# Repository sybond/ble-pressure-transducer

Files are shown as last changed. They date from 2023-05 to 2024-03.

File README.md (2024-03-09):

# Bluetooth Pressure Transducer
The purpose of this project is to create Bluetooth Pressure Transducer that can be connected to pressure profiling apps (SE Profiler, Coffee Flow & Odyssey Espresso).

The target espresso machine was my Flair 58. This espresso maker has a G1/8 fitting for the pressure gauge.

## Diagram
Following diagram depict the configuration of the current implementation.

```mermaid
flowchart BT
    A(Analog Pressure\nTransmitter) <-->|wired| B(ESP32 Dev Board)
    B<.->|BLE/Bluetooth|C(Android/iPhone\nSE Profiler, Coffee Flow, Odyssey Espresso Apps)
```

## Bill of Material
This device consist of following components:
- ESP32 Dev board (WEMOS LOLIN32 OLED)
- Breadboard
- Analog Pressure Transmitter 5V DC

### ESP32 Dev board (WEMOS LOLIN32 OLED)
I'm using this board because there is OLED embedded in the board so we just need the programming part without having trouble to do wiring on display component.

The display component will be used to display the current status of the device. Whether connected to the app or not. Also to display current pressure reading by the analog pin.

ESP32 LOLIN32

ESP32 LOLIN32

### Analog Pressure Transmitter 5V DC
`WARNING: Make sure youre using high temperature version of the sensors before using it with your espresso machine`

The analog pressure transmitter wiring will have :
- 5V (power)
- Ground
- Output

[@frontmesh](https://github.com/frontmesh) has provided some information regarding two types of G1/8 fittings, short and long. I'm guessing Flair 58 is using the lengthy version. It would be preferable if you could have this long-fitting version &mdash; and please share it with us.

### Wiring
From above schematic, we will need to connect Pressure Transmitter to `5V`, `GND` and some analog PIN (I choose `ADC19`/`GPIO26`).

### Code Part
At the moment I will put only the binary to this repository. However the snippet for pressure calculation is availbale in the repository.

### Flashing Firmware using ESPTOOL
Download the binary provided in the release section. The binary will consists of following files:
1. `BluetoothPressureTransducer_InternalLCD.ino.bootloader.bin`
2. `BluetoothPressureTransducer_InternalLCD.ino.partitions.bin`
3. `BluetoothPressureTransducer_InternalLCD.ino.bin`
4. `boot_app0.bin` (this files should be provided by ESPTOOL during package installation - make sure your environment already have running Arduino IDE with ESP32 pack)

Run following command (some parts will need you to adjust to match your own environment):

```shell
{PATH_TO_ESPTOOL}/esptool --chip esp32 --port "{CHANGE_TO_YOUR_DEVICE_PORT}" --baud 115200  --before default_reset --after hard_reset write_flash  -z --flash_mode dio --flash_freq 80m --flash_size 4MB 0x1000 BluetoothPressureTransducer_InternalLCD.ino.bootloader.bin 0x8000 BluetoothPressureTransducer_InternalLCD.ino.partitions.bin 0xe000 "{PATH_TO_YOUR_ESP32_PACKAGE}/packages/esp32/hardware/esp32/2.0.7/tools/partitions/boot_app0.bin" 0x10000 BluetoothPressureTransducer_InternalLCD.ino.bin
```

For your reference, in my environment (OSX) will need to run using following parameters:
```shell
"/Users/sybond/Library/Arduino15/packages/esp32/tools/esptool_py/4.5.1/esptool" --chip esp32 --port "/dev/cu.usbserial-0001" --baud 115200  --before default_reset --after hard_reset write_flash  -z --flash_mode dio --flash_freq 80m --flash_size 4MB 0x1000 "/private/var/folders/pz/jkl6w3fs45v88wcck8qtfhw00000gn/T/arduino/sketches/4E4A8C476EDC2D7C933461960E7BD641/BluetoothPressureTransducer_InternalLCD.ino.bootloader.bin" 0x8000 "/private/var/folders/pz/jkl6w3fs45v88wcck8qtfhw00000gn/T/arduino/sketches/4E4A8C476EDC2D7C933461960E7BD641/BluetoothPressureTransducer_InternalLCD.ino.partitions.bin" 0xe000 "/Users/sybond/Library/Arduino15/packages/esp32/hardware/esp32/2.0.7/tools/partitions/boot_app0.bin" 0x10000 "/private/var/folders/pz/jkl6w3fs45v88wcck8qtfhw00000gn/T/arduino/sketches/4E4A8C476EDC2D7C933461960E7BD641/BluetoothPressureTransducer_InternalLCD.ino.bin"
```
Currently I have 2 versions of firmware:
1. For 0-200psi pressure transmitter (discontinued)
2. For 0-1,6MPa pressure transmitter (I recently purchase from [here](https://www.aliexpress.com/item/1005004559608411.html); make sure to put note about G1/8 fitting)

## Config Characteristic
Latest version of the firmware, now support of write Config Characteristic (`873ae82d-4c5a-4342-b539-9d900bf7ebd0`). The purpose of this characteristic is to able customized sensor reading based on the manual calibration. The characteristic expecting following data:

| Config parameter | Format | Sample |
|:---|:---| :--- |
| minADC | `00 {4 bytes int}` | `00 c7 01 00 00` = set minVoltage to 455|
| maxADC | `01 {4 bytes int}` | `01 34 0d 00 00` = set maxADC to 3380|
| maxMilibar | `02 {8 bytes long}` | `02 80 3e 00 00 00 00 00 00` = set maxMilibar to 16000|

The parameters will be involved into following calculation to determine pressure value:

`pressure in milibar =  (analogReading - minADC) * (maxMilibar) / (maxADC - minADC);`

Following is the default parameters value:
1. Minimum ADC (`minADC` default value is `455`)
2. Maximum ADC (`maxADC` default value is `3380`)
3. Maximum milibar (`maxMilibar` default value is `9000`)

The default value is the working parameter for current pressure sensor I use (0.5V-4,5V, 0-1,6Mpa).

## Serial Config Interface
Other option starting from v3.0, you can configure the parameters via serial interface.

1. Just connect to the ESP32 Bluetooth using Serial Bluetooth Terminal ([Android](https://play.google.com/store/apps/details?id=de.kai_morich.serial_bluetooth_terminal)) or another similiar apps.
2. Type `info`. The syntax structure should be self explaining from this point.

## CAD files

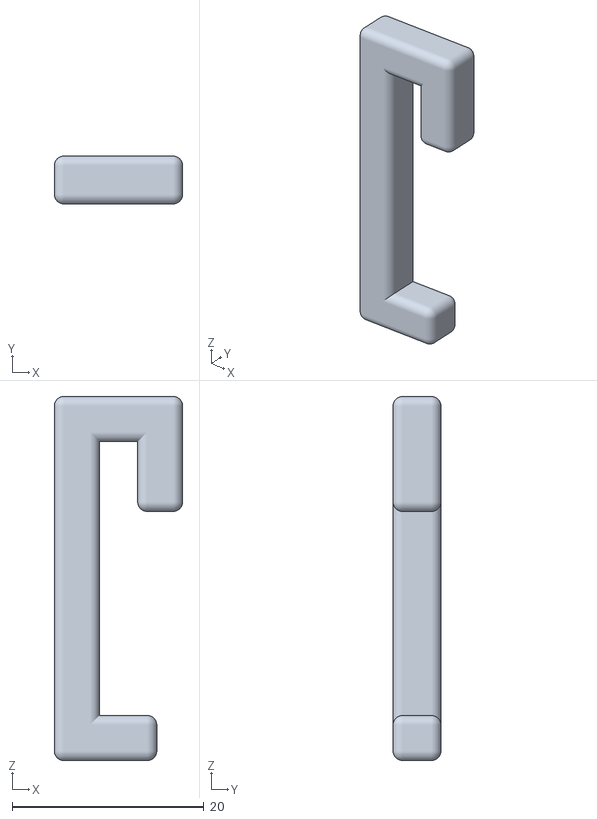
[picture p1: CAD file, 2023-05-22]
WEMOSLolin32_Case/skadisHook.stl
13.4 x 5.00 x 38.0

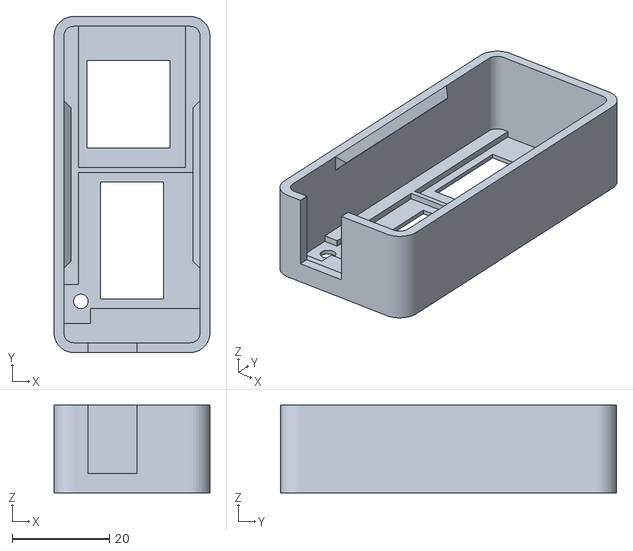
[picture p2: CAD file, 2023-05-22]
WEMOSLolin32_Case/Lolin32 Box v2.stl
32.0 x 69.0 x 18.0

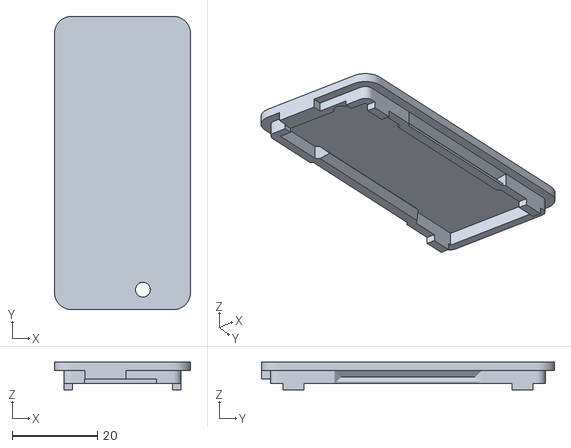
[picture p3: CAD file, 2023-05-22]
WEMOSLolin32_Case/esp32_oled_cover_param.stl
32.0 x 69.0 x 6.50

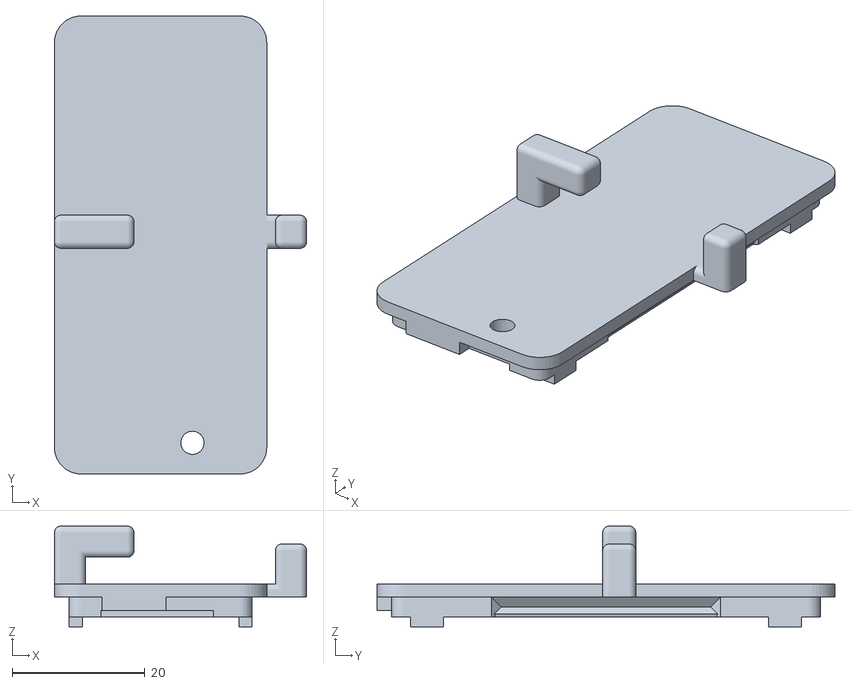
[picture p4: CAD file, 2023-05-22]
WEMOSLolin32_Case/Lolin32 Cover v2.stl
38.0 x 69.0 x 15.2

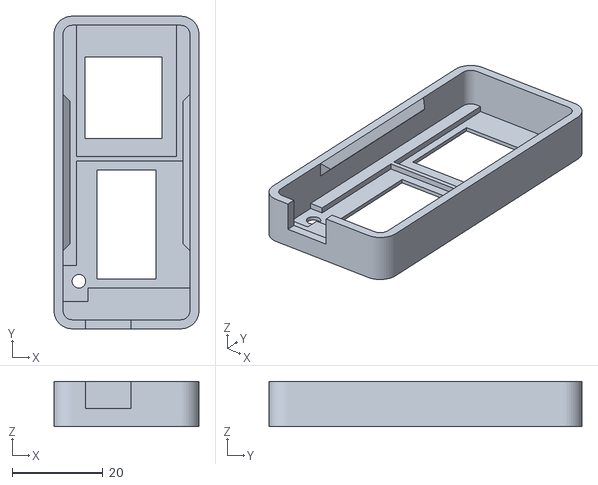
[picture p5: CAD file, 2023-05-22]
WEMOSLolin32_Case/esp32_oled_box_param.stl
32.0 x 69.0 x 10.0

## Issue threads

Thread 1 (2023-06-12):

Flair58 connector

frontmesh, 2023-06-12:
Hi @sybond ,

I've seen your post in some of the groups and was wondering to try this out with my Flair 58.
Transducer which you purchased (as stated in README - https://www.aliexpress.com/item/1005004559608411.html) doesn't have proper flair 58 pressure thread connection. Did you have to buy some sort of adapter so that you were able to use it with your Flair 58?
Another solution to prevent leaks from the thread would be to use sealant tape which should be put on to the thread every time you change the pressure device which I am trying to avoid.

Thanks,
Vlad

sybond, 2023-06-12:
> Did you have to buy some sort of adapter so that you were able to use it with your Flair 58?

No. Make sure you ordering G1/8. They mention _"Pressure connection: 1/8”NPT, Other pressure connection is on request"_.

> Another solution to prevent leaks from the thread would be to use sealant tape which should be put on to the thread every time you change the pressure device which I am trying to avoid.

Even though I have ordered the correct G1/8, I still use seal tape to prevent leaks. In my case, I'll stick to my pressure sensor, even if I don't record the data every time.

frontmesh, 2023-06-12:
Thanks for the clarification. I have indeed received a G1/8 connection then.
What I did not release is there are two types (short and long) of G1/8 connections.
Flair uses longer connection with a rubber ring at the top which prevents leaks
https://pressensor.com/products/fitting-for-compatibility-with-g1-8-connections
and a short one https://pressensor.com/products/fitting-for-compatibility-with-g1-8-short-connections
I have another digital Elitech PGW-500 transducer which also has short G1/8 connection.

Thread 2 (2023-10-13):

Temp readings?

browntownington, 2023-10-13:
Hey there, fellow flair 58 user.. been trying to find myself a low cost pressure transducer for months and I'm very grateful to come across your project.

I noticed alot of commercially available transducers also read temp. I thought this would be cool for the flair since temp is always a guess from the kettle and the boiler. Have you considered tracking temp?

I haven't been successful in finding a transmitter that does pressure and temp. So I'm guessing an additional BSP sensor would be required.

sybond, 2023-10-25:
Hi!
Actually I was thinking to read the temp from the OEM sensor that currently only connected to the F58 controller.
I see in Facebook group discussion they are using N type thermocouple.

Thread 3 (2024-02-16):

Voltage of Pressure Transmitter

GelliFrancesco, 2024-02-16:
Hi Bondan,
Thanks a lot for your contribution, I think you are helping the community a lot!

I am looking into the 0-1,6MPa pressure transmitter you recommended:(https://www.aliexpress.com/item/1005004559608411.html)
It comes in various Voltage options: 0-3.3V, 0-5V, 1-5V and 0.5-4.5V

Which one do you recommend buying?
I see that the ESP32 kit has a 5V In pin, but I read that most ESP32 kits works only at 3.3V, hence I am a bit confused.
Thanks!

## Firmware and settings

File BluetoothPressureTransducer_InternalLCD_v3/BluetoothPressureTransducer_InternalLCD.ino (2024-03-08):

/*

 Bluetooth Pressure Transducer
 Copyright (c) 2023 Bondan Sumbodo <sybond@gmail.com>

 FOR WEMOS LOLIN32

 History:
 2023/03/23 - First version : playing with BLE characteristic
 2023/03/24 - Adding Pressure BLECharacteristic, Battery Level BLECharacteristic
            - Fix pressure data format encoding
 2023/03/30 - Rewrite for WEMOS LOLIN32 board
            - Adding logo
            - New calculation of pressure, since in LOLIN32 they have 5V input for sensor
 2023/05/01 - Allow to display pressure without waiting BLE connected
 2024/02/23 - Saving last minVoltage into NVS
 2024/02/24 - Revisit pressure calculation
            - Adding minVoltage, maxVoltage, maxMilibar to NVS
            - Adding characteristic for future use, currently to reset NVS stored value to default value
 2024/02/28 - Adding new calibrated point for ADC known value for 9 Bar pressure
 2024/03/08 - Rework on configuration part. Removing `minVoltage` and `maxVoltage`.
            - Adding serial com settings
            - All pressure calculation now should be configurable using `map(analogValue,minADC,maxADC,0,maxMilibar)`.

*/
#include <BLEDevice.h>
#include <BLEServer.h>
#include <BLEUtils.h>
#include <BLE2902.h>

#include <Adafruit_GFX.h>
#include <Adafruit_SSD1306.h>

#include <Preferences.h>

BLEServer* pServer = NULL;
BLECharacteristic* pCharPressure = NULL;
BLECharacteristic* pCharZeroPressure = NULL;
BLECharacteristic* pCharPressureConfig = NULL;
BLECharacteristic* pCharBatt = NULL;
BLECharacteristic* pCharLog = NULL;
BLECharacteristic* pCharMFC = NULL;


#define SCREEN_WIDTH 128     // OLED display width, in pixels
#define SCREEN_HEIGHT 64     // OLED display height, in pixels
#define OLED_RESET -1        // Reset pin # (or -1 if sharing Arduino reset pin)
#define SCREEN_ADDRESS 0x3C  ///< See datasheet for Address; 0x3D for 128x64, 0x3C for 128x32
Adafruit_SSD1306 display(SCREEN_WIDTH, SCREEN_HEIGHT, &Wire, OLED_RESET);

bool deviceConnected = false;
bool oldDeviceConnected = false;
bool printLog = false;
int BattLevel = 100;
int32_t value = 0xB6032823;
int32_t value2 = 0x00;
int barPotentio = 0;
int counter = 0;

float minVoltage = 0.5;
float maxVoltage = 4.5;
float currVoltage = 0;
long maxMilibar = 16000;  //default 16bar

int Potentio = 0;
float currBar = 0.0;

uint8_t pressData[4] = { 0x03, 0xb6, 0x0, 0x0 };
char text[200];
char dev_name[20];
Preferences configNVS;


#define fw_ver "v2.6 WL"

static unsigned char logosybond_led_bits[] = {
  0x00, 0x00, 0x00, 0x00, 0x00, 0x00, 0xe0, 0x01, 0x00, 0x00, 0x00, 0x70,
  0x00, 0x00, 0x00, 0x00, 0x00, 0x00, 0x00, 0xe0, 0x01, 0x00, 0x00, 0x00,
  0x70, 0x00, 0xc0, 0xff, 0xff, 0x07, 0x00, 0x00, 0xe0, 0x01, 0x00, 0x00,
  0x00, 0x70, 0x00, 0xf0, 0xff, 0xff, 0x1f, 0x00, 0x00, 0xe0, 0x01, 0x00,
  0x00, 0x00, 0x70, 0x00, 0xf8, 0xff, 0xff, 0x3f, 0x00, 0x00, 0xe0, 0x01,
  0x00, 0x00, 0x00, 0x70, 0x00, 0xfc, 0xff, 0xff, 0x7f, 0x00, 0x00, 0xe0,
  0x01, 0x00, 0x00, 0x00, 0x70, 0x00, 0x3e, 0x00, 0x00, 0x7c, 0xe0, 0x3f,
  0xfc, 0x3f, 0xfc, 0xf8, 0xc7, 0x7f, 0x00, 0x1e, 0x00, 0x00, 0xfb, 0xf0,
  0x7f, 0xfe, 0x7f, 0xfe, 0xf9, 0xef, 0x7f, 0x00, 0x1f, 0x00, 0x80, 0xf7,
  0x70, 0x7a, 0xfe, 0xff, 0xff, 0xfb, 0xef, 0x7f, 0x00, 0x0f, 0xe0, 0x87,
  0xf7, 0xf0, 0xf1, 0xef, 0xf1, 0xc7, 0x3f, 0xfe, 0x78, 0x00, 0x0f, 0xf8,
  0x1f, 0xf7, 0xe0, 0xf3, 0xef, 0xf1, 0x87, 0x3f, 0xfe, 0x70, 0x00, 0x0f,
  0xfc, 0x7f, 0xf0, 0xc0, 0xe7, 0xe7, 0xf1, 0x87, 0x3f, 0xfe, 0x78, 0x06,
  0x0f, 0xfe, 0x7f, 0xf0, 0xb0, 0xc7, 0xe7, 0xff, 0xff, 0x3b, 0xee, 0x7f,
  0x0f, 0x0f, 0x3f, 0xfc, 0xf0, 0xf0, 0xc7, 0xe3, 0x7f, 0xfe, 0x39, 0xee,
  0x7f, 0x0f, 0x0f, 0x1f, 0xf0, 0xf1, 0xf0, 0xc3, 0xe3, 0x3f, 0xfc, 0x38,
  0xce, 0x7f, 0x0f, 0x8f, 0x0f, 0xe0, 0xf1, 0x00, 0xe0, 0x01, 0x08, 0x00,
  0x00, 0x00, 0x00, 0x00, 0x8f, 0x07, 0xe0, 0xf1, 0x00, 0xe0, 0x01, 0x00,
  0x00, 0x00, 0x00, 0x00, 0x00, 0x8f, 0x07, 0xe0, 0xf1, 0x00, 0xf0, 0x00,
  0x00, 0x00, 0x00, 0x00, 0x00, 0x00, 0x8f, 0x07, 0xe0, 0xf1, 0x00, 0xf0,
  0x00, 0x00, 0x00, 0x00, 0x00, 0x00, 0x00, 0x8f, 0x07, 0xe0, 0xf1, 0xe0,
  0xff, 0xcf, 0x3f, 0x3f, 0x00, 0x00, 0x00, 0x00, 0x8f, 0x0f, 0xe0, 0xf1,
  0xf0, 0xff, 0xdf, 0xbf, 0x7f, 0x00, 0x00, 0x00, 0x00, 0x0f, 0x0f, 0xf0,
  0xf1, 0x70, 0xfa, 0xff, 0xdf, 0xff, 0x00, 0x00, 0x00, 0x00, 0x0f, 0x1f,
  0xf8, 0xf0, 0xf0, 0x79, 0xfc, 0xe3, 0xf1, 0x00, 0x00, 0x00, 0x00, 0x0f,
  0xfe, 0x7f, 0xf0, 0xe0, 0x7b, 0xfc, 0xe3, 0xf1, 0x00, 0x00, 0x00, 0x00,
  0x0f, 0xfc, 0x7f, 0xf0, 0xc0, 0x7f, 0xfc, 0xe3, 0xf1, 0x00, 0x00, 0x00,
  0x00, 0x0f, 0xf8, 0x1f, 0xf0, 0xb0, 0xff, 0xff, 0xc3, 0xff, 0x00, 0x00,
  0x00, 0x00, 0x0f, 0xe0, 0x0f, 0xf0, 0xf0, 0xff, 0xdf, 0xc3, 0x7f, 0x00,
  0x00, 0x00, 0x00, 0x0f, 0x00, 0x00, 0xf0, 0xf0, 0xfb, 0xcf, 0x83, 0x3f,
  0x00, 0x00, 0x00, 0x00, 0x1f, 0x00, 0x00, 0xf8, 0xc0, 0x78, 0x02, 0x00,
  0x04, 0x00, 0x00, 0x00, 0x00, 0x3e, 0x00, 0x00, 0x7c, 0x00, 0x78, 0x00,
  0x00, 0x00, 0x00, 0x00, 0x00, 0x00, 0xfc, 0xff, 0xff, 0x7f, 0x00, 0x78,
  0x00, 0x00, 0x00, 0x00, 0x00, 0x00, 0x00, 0xfc, 0xff, 0xff, 0x3f, 0x00,
  0x78, 0x00, 0x00, 0x00, 0x00, 0x00, 0x00, 0x00, 0xf0, 0xff, 0xff, 0x1f,
  0x00, 0x70, 0x00, 0x00, 0x00, 0x00, 0x00, 0x00, 0x00, 0xe0, 0xff, 0xff,
  0x07, 0x00, 0x00, 0x00, 0x00, 0x00, 0x00, 0x00, 0x00, 0x00
};


class MyServerCallbacks : public BLEServerCallbacks {
};

class MyPressChCallbacks : public BLECharacteristicCallbacks {
};

class MyConfigChCallbacks : public BLECharacteristicCallbacks {
};


void prepDisplay() {
  Wire.begin(5, 4);
  // SSD1306_SWITCHCAPVCC = generate display voltage from 3.3V internally
  if (!display.begin(SSD1306_SWITCHCAPVCC, SCREEN_ADDRESS)) {
    Serial.println(F("SSD1306 allocation failed"));
    for (;;)
      ;  // Don't proceed, loop forever
  }

  // Show initial display buffer contents on the screen --
  // the library initializes this with an Adafruit splash screen.
  display.clearDisplay();
  display.setTextSize(1);               // Normal 1:1 pixel scale
  display.setTextColor(SSD1306_WHITE);  // Draw white text
  display.setCursor(0, 0);              // Start at top-left corner
  display.cp437(true);                  // Use full 256 char 'Code Page 437' font
  display.display();
  delay(2000);  // Pause for 2 seconds
}

void setup() {
 // ----- stripped -------
}

float getSensorvalue(int analoge) {
  int adc_value_final = 0;
  int adc_samples = 64;
  int min_adc = (minVoltage * 4095) / maxVoltage;
  for (int i = 0; i < adc_samples; i++) {
    adc_value_final += analogRead(analoge);
  }
  adc_value_final /= adc_samples;
  if (adc_value_final < min_adc) { adc_value_final = min_adc; }
  currVoltage = (adc_value_final * 4.5) / 4095.0;
  float bar = map(adc_value_final, min_adc, 4095, 0, maxMilibar * 10);
  if (printLog) {
    Serial.printf("Analog:%d, Vol:%.2fV, miliBar:%.2f\n", adc_value_final, currVoltage, bar / 10);
  }
  delay(100);
  return bar / 10;
}

//--------- the main loop -------
void loop() {
// ------ stripped --------------
}

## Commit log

2023-04-30 Update README.md
    Adding some details about dev board and pressure transmitter sensor
2023-05-22 Adding 3D print model case for the board
    [Lolin32 Box v2.stl, Lolin32 Cover v2.stl, esp32_oled_box_param.stl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]
2024-02-25 Update on pressure calculation.
